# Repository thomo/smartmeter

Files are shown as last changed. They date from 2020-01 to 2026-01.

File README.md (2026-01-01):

# SmartMeter Gateway

A complete hardware solution for reading data from smart energy meters via their optical interface. This project provides the PCB designs for an IR read/write head and an ESP8266-based controller board designed to run **Tasmota**.

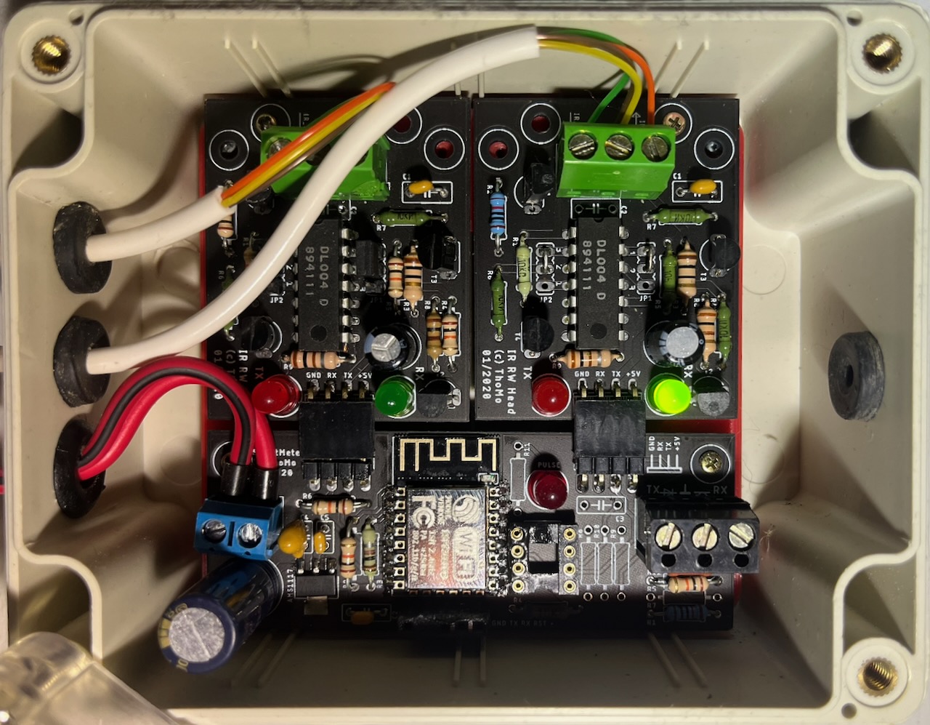
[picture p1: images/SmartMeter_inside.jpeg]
Assembled SmartMeter Gateway

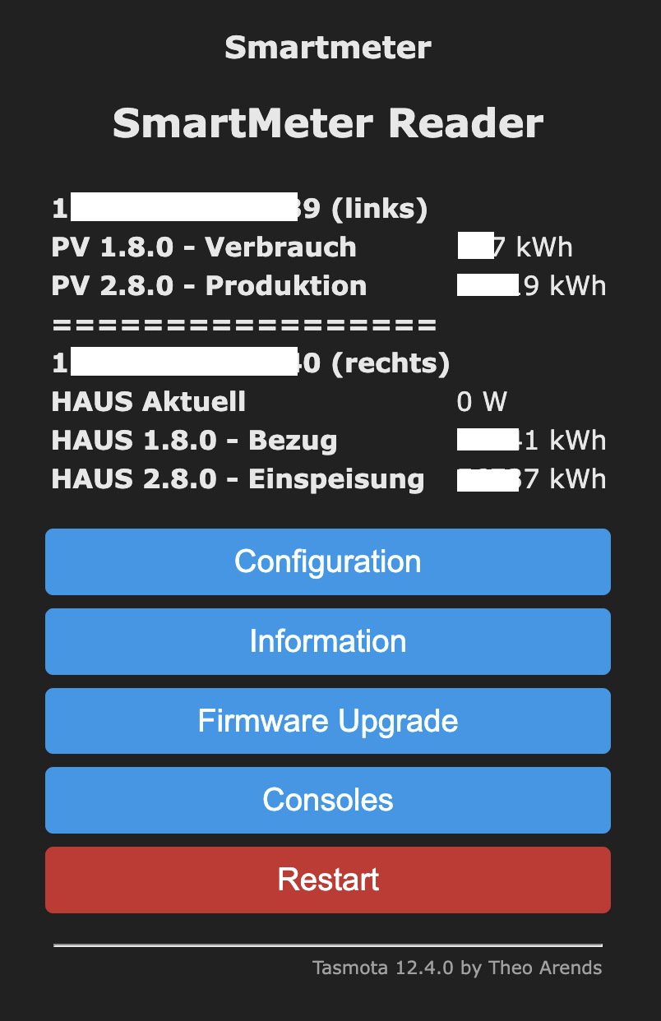
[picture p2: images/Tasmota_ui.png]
Tasmota UI


## Overview

The SmartMeter Gateway consists of two primary components:
1.  **IR Read/Write Head**: An optical probe that attaches to the smart meter's IR port.
2.  **ESP8266 Controller Board**: A carrier board for an ESP8266 module (e.g., ESP-12F) that processes the IR signals and provides a network interface via Wi-Fi.

By running Tasmota on the ESP8266, the meter data can be easily integrated into Home Automation systems like **Home Assistant**, **OpenHAB**, or **ioBroker** using MQTT or REST API.

## Hardware

The PCB designs are located in the `board` directory. These files were created with Autocad Eagle.

### 1. IR Read/Write Head (`board/ir_rw_head`)
The IR head is responsible for the physical communication with the energy meter.
- **Schematic**: [ir_rw_head_circuit.pdf](board/ir_rw_head_circuit.pdf)
- **Files**: Eagle schematic (`.sch`) and PCB layout (`.brd`).
- **Visuals**: 
    - [Top View](board/ir_rw_head_pcb_top.png)
    - [Bottom View](board/ir_rw_head_pcb_bottom.png)

### 2. ESP8266 Controller Board (`board/smartmeter`)
The main board that houses the ESP8266 and connects to the IR head.
- **Schematic**: [smartmeter_circuit.pdf](board/smartmeter_circuit.pdf)
- **Files**: Eagle schematic (`.sch`) and PCB layout (`.brd`).
- **Visuals**:
    - [Top View](board/smartmeter_pcb_top.png)
    - [Bottom View](board/smartmeter_pcb_bottom.png)

## Software / Firmware

The board is designed to be used with the [Tasmota](https://tasmota.github.io/docs/) firmware.

### Configuration
1. Build a customized tasmota image with SML/OBIS support 
   - see [Tasmota Smart Meter Interface](https://tasmota.github.io/docs/Smart-Meter-Interface/)
   - see [HOW TO: TASMOTA SML](https://docs.google.com/document/d/1olSGZcaE_vkdNXzN_p0zGee61xKCcK3HJe3Al00xj2g/edit?usp=sharing).
2. Configure the GPIOs for the IR receiver and transmitter.
```tasmota  
{"NAME":"Smartmeter","GPIO":[1,1,1,1,1,1,1,1,0,0,1,1,1,0],"FLAG":0,"BASE":18}
```

3. Use a Tasmota Script (SML) to decode the specific data format of your energy meter (e.g., SML or OBIS) - do not forget to enable the "Enable Script" checkbox. 

Example Tasmota SML script snippet:
```tasmota
>D

>B
=>sensor53 r
>M 2
+1,13,s,0,9600,Haus
+2,12,s,0,9600,PV

;1,77070100100700FF@1,Aktuell,W,Power_curr,0
1,77070100010800FF@1000,Bezug,kWh,Tariflos,2
1,77070100020800FF@1000,Einspeisung,kWh,Tariflos,2
2,=h============
;2,77070100100700FF@1,Aktuell,W,Power_curr,0
2,77070100010800FF@1000,Verbrauch,kWh,Tariflos,2
2,77070100020800FF@1000,Produktion,kWh,Tariflos,2
#
```

## Assembly

Detailed images of the assembled boards can be found in the `images` folder.
- [Inside View](images/SmartMeter_inside.jpeg)

## License

Standard open-source licenses apply. See design files for details.

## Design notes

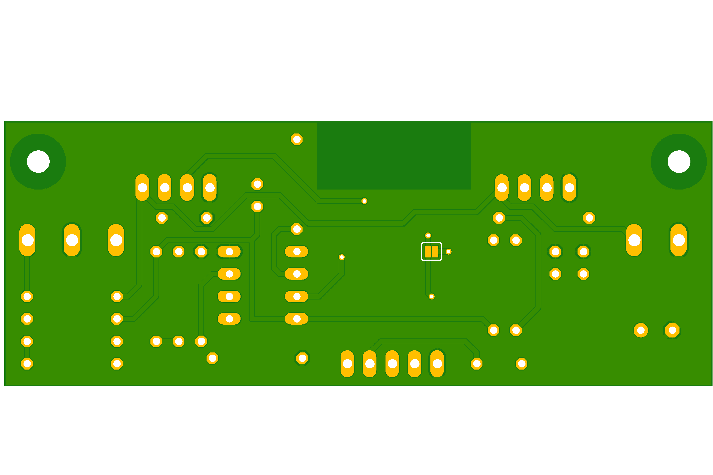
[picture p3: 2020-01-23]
board/smartmeter_pcb_bottom.png

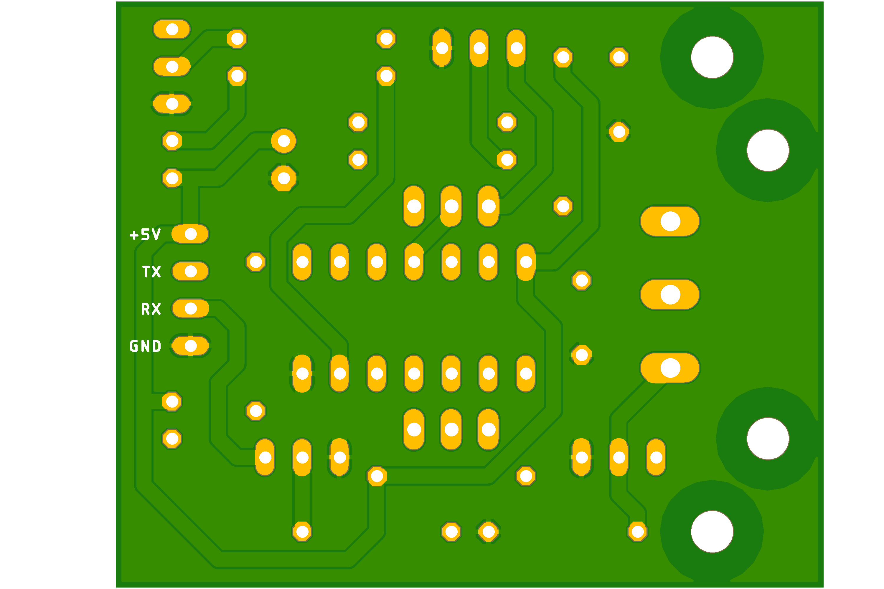
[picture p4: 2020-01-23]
board/ir_rw_head_pcb_bottom.png

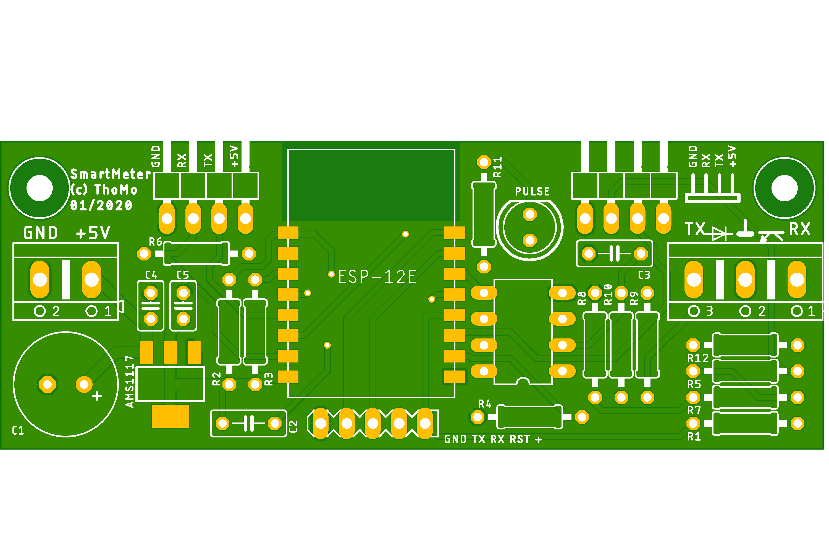
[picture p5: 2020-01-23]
board/smartmeter_pcb_top.png

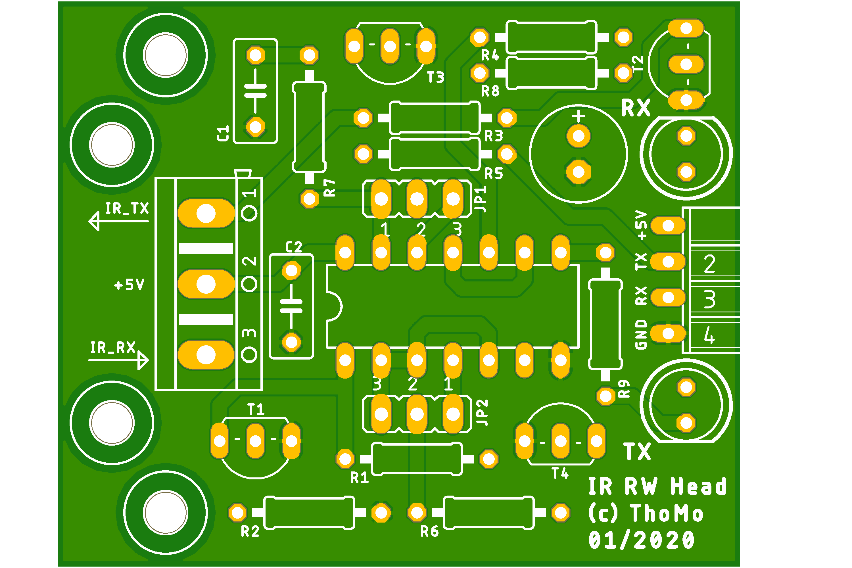
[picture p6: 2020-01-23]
board/ir_rw_head_pcb_top.png

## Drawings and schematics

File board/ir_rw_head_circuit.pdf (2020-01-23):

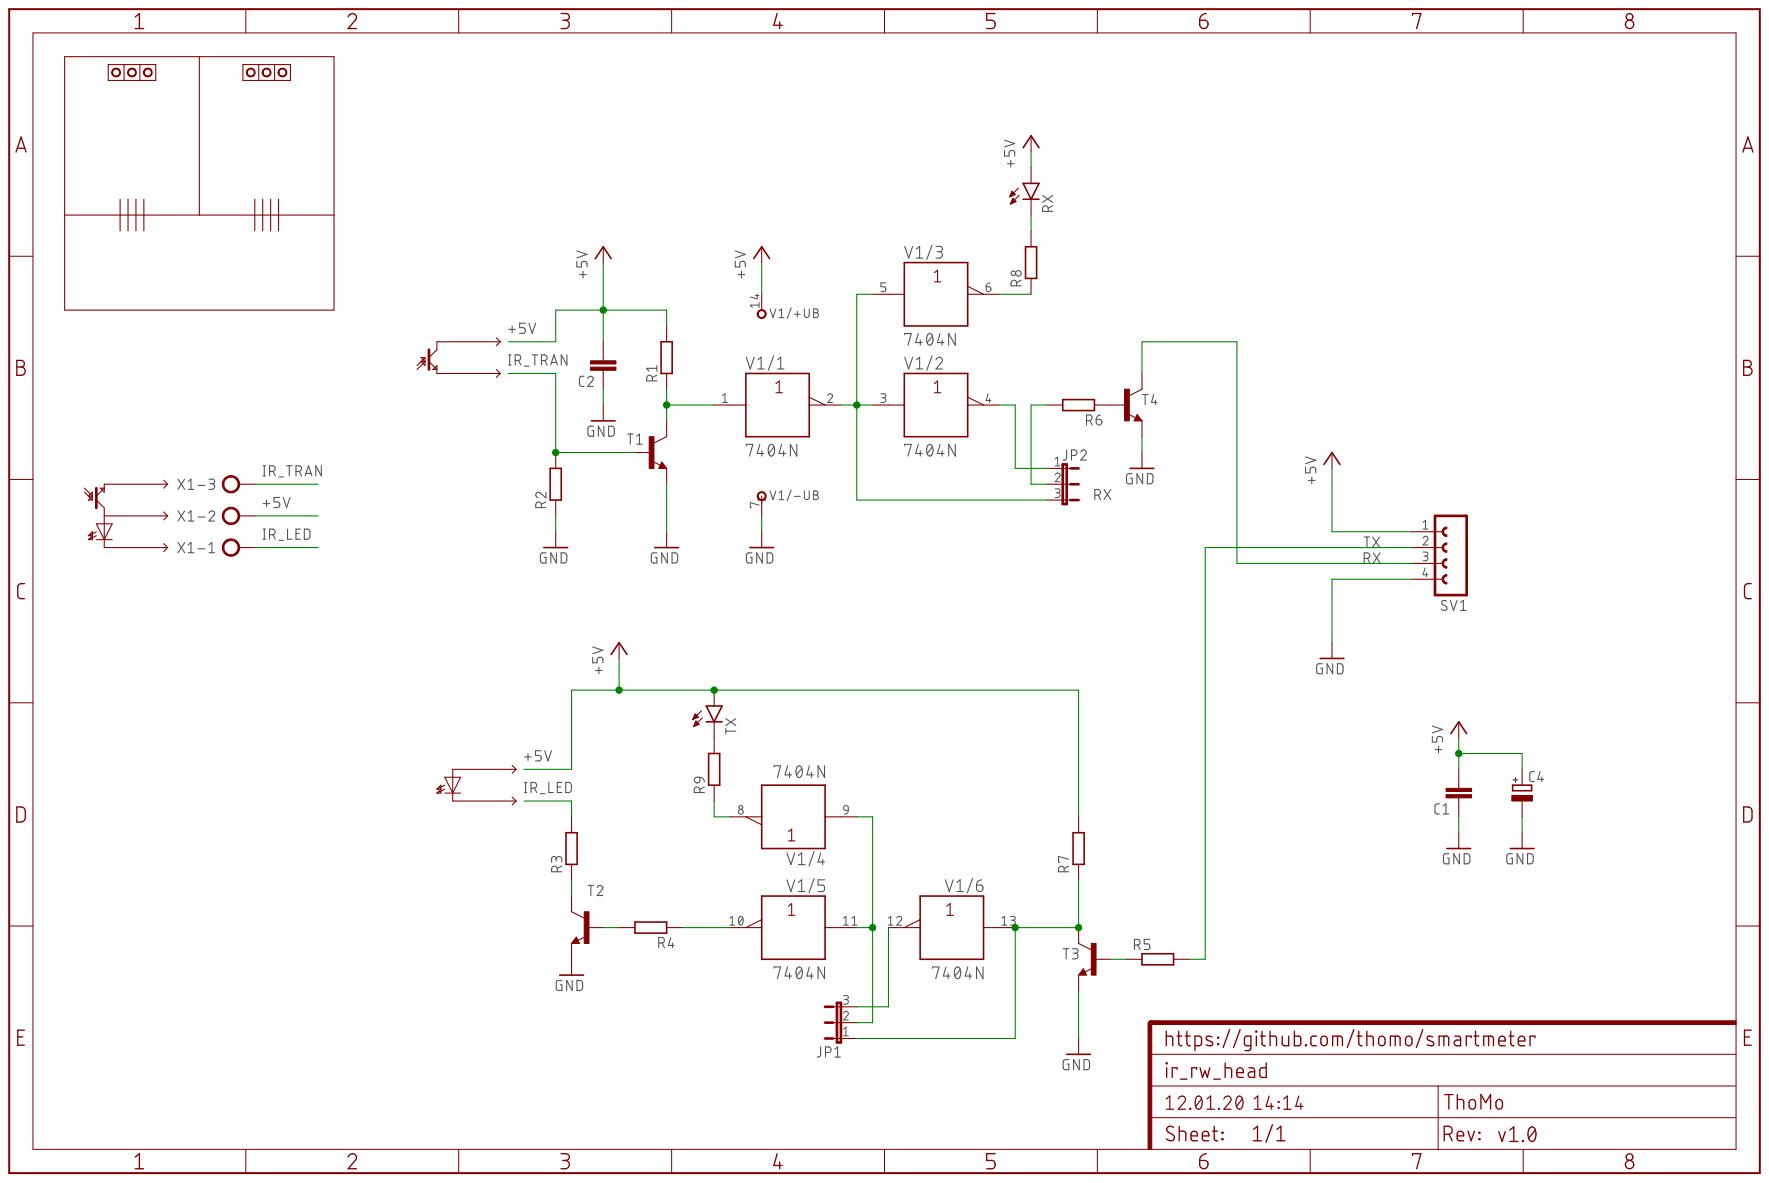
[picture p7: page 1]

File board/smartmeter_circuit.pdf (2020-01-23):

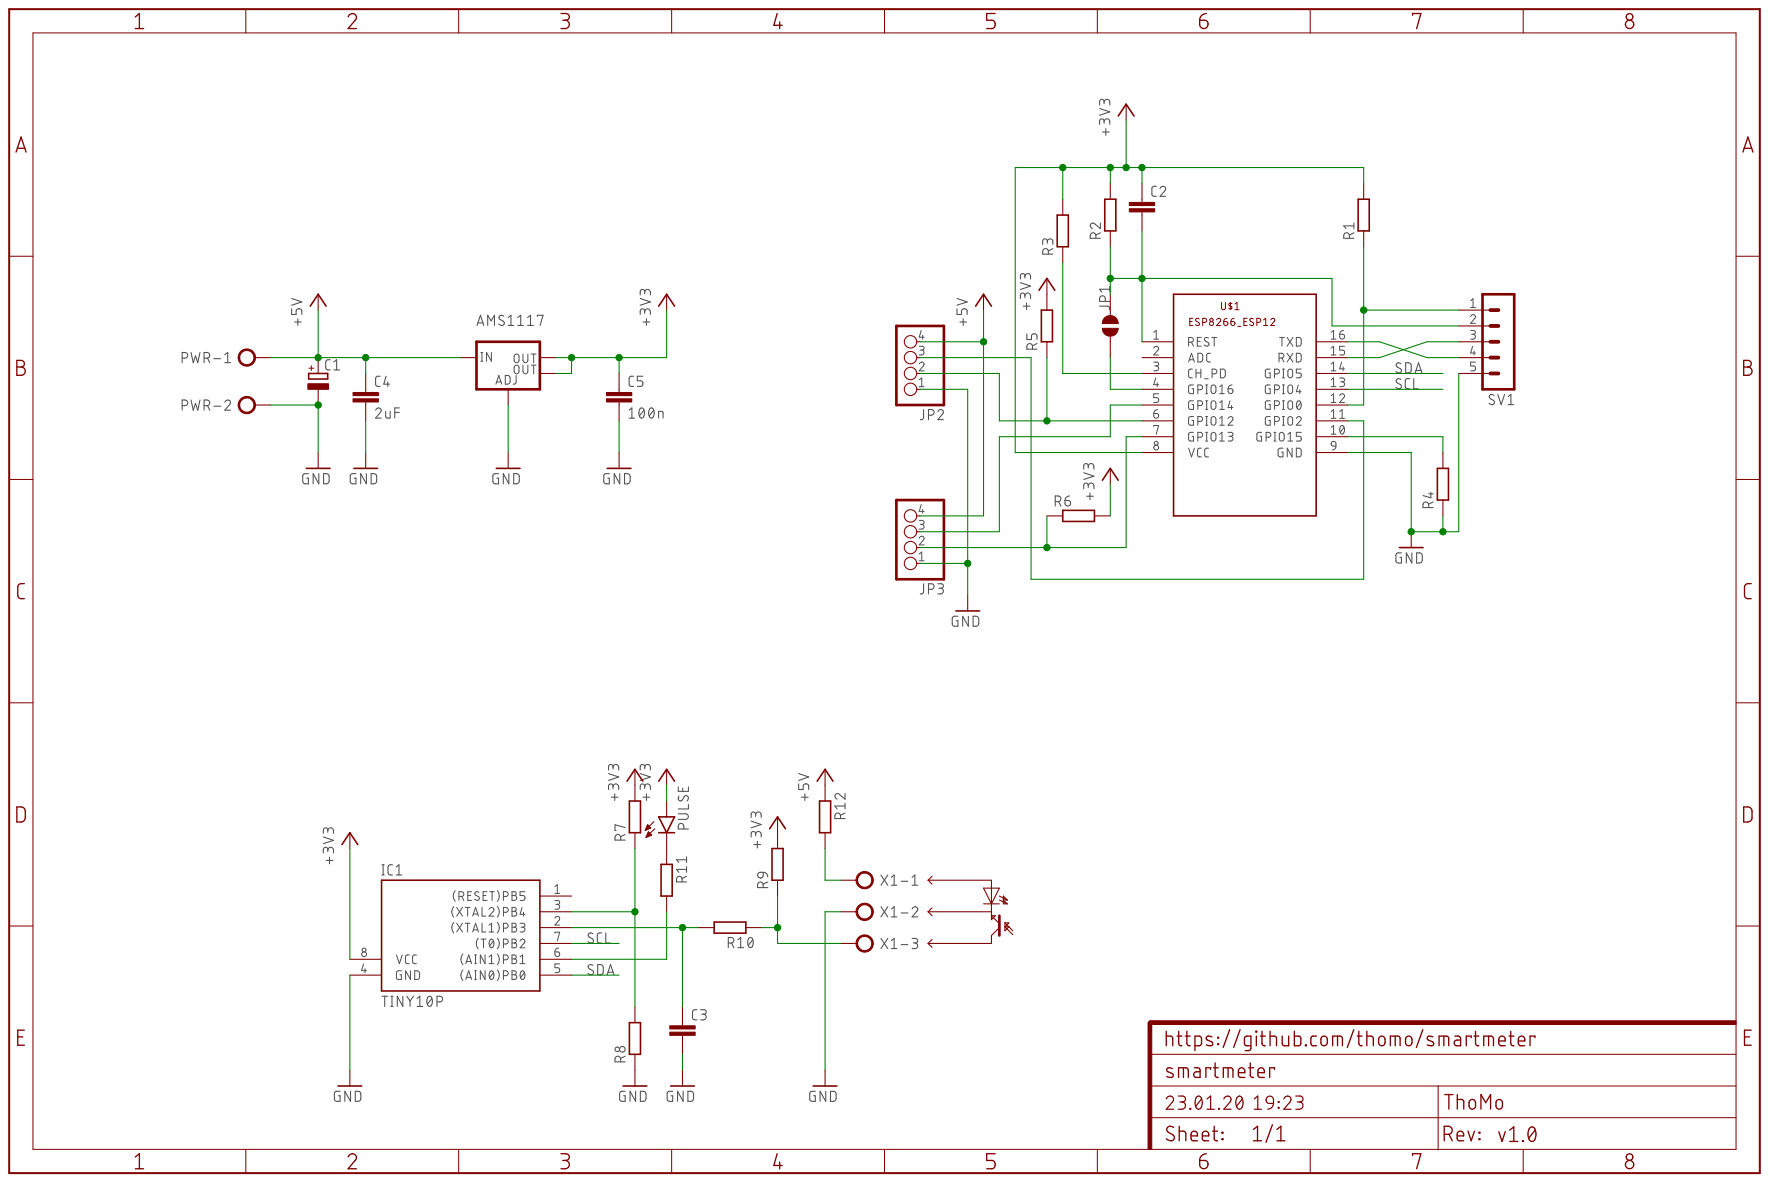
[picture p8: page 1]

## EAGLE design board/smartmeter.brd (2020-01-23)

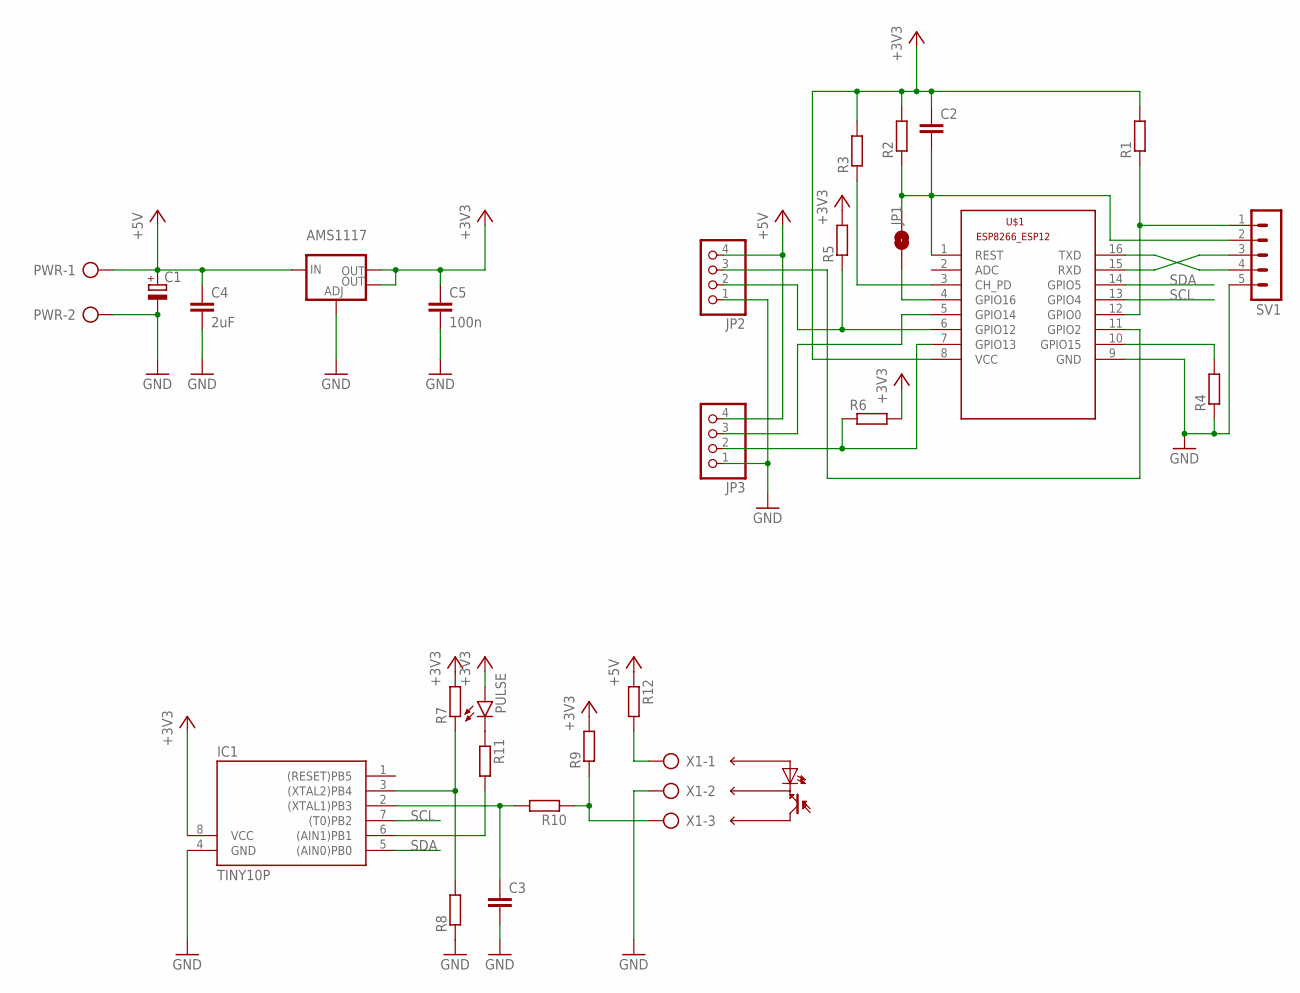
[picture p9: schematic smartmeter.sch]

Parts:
AMS1117: V_REG_LM1117SOT223; SOT223
C1: CPOL-EUE3.5-10; E3,5-10
C2, C3: C-EU050-025X075; C050-025X075
C4: 2uF; C025-025X050
C5: 100n; C025-025X050
IC1: TINY10P; DIL08
JP1: JUMPER-SMT_2_NO_SILK; SMT-JUMPER_2_NO_SILK
JP2, JP3: PINHD-1X4/90; 1X04/90
PULSE: LED5MM
PWR: AK500/2
R1, R2, R3, R4, R5, R6, R7, R8, R9, R10, R11, R12: R-EU_0207/10; 0207/10
SV1: MA05-1
U$1: ESP8266-12; ESP8266-ESP12
X1: AK500/3

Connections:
+3V3: AMS1117.2 (OUT), AMS1117.4 (OUT), C2.1, C5.1, IC1.8 (VCC), PULSE.A, R1.2, R2.2, R3.2, R5.2, R6.2, R7.2, R9.2, U$1.8 (VCC)
+5V: AMS1117.3 (IN), C1.+, C4.1, JP2.4, JP3.4, PWR.1, R12.1
GND: AMS1117.1 (ADJ), C1.-, C3.2, C4.2, C5.2, IC1.4 (GND), JP2.1, JP3.1, PWR.2, R4.1, R8.1, SV1.5, U$1.9 (GND), X1.2
unnamed: R1.1, SV1.1, U$1.12 (GPIO0)
unnamed: C2.2, JP1.2, R2.1, SV1.2, U$1.1 (REST)
unnamed: R4.2, U$1.10 (GPIO15)
unnamed: JP1.1, U$1.4 (GPIO16)
unnamed: R3.1, U$1.3 (CH_PD)
unnamed: SV1.4, U$1.16 (TXD)
unnamed: SV1.3, U$1.15 (RXD)
unnamed: C3.1, IC1.2 ((XTAL1)PB3), R10.2
unnamed: IC1.3 ((XTAL2)PB4), R7.1, R8.2
unnamed: JP2.3, U$1.11 (GPIO2)
unnamed: JP2.2, R5.1, U$1.6 (GPIO12)
unnamed: JP3.3, U$1.5 (GPIO14)
unnamed: JP3.2, R6.1, U$1.7 (GPIO13)
unnamed: R9.1, R10.1, X1.3
unnamed: IC1.6 ((AIN1)PB1), R11.2
unnamed: PULSE.K (C), R11.1
unnamed: R12.2, X1.1
SCL: IC1.7 ((T0)PB2), U$1.13 (GPIO4)
SDA: IC1.5 ((AIN0)PB0), U$1.14 (GPIO5)

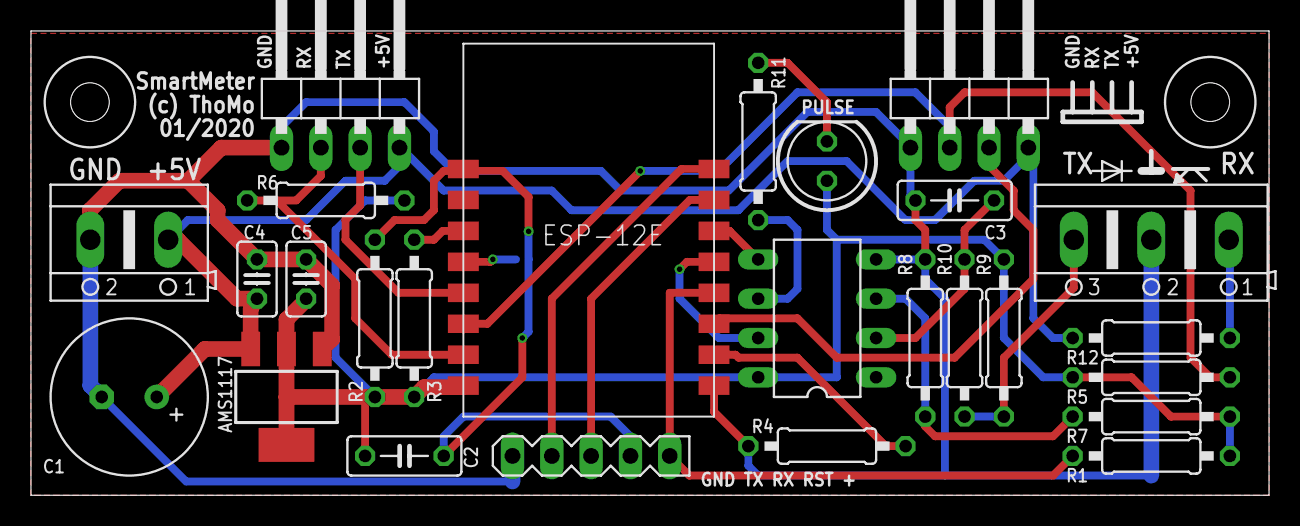
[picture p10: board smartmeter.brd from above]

Board: 2 copper layers, 80.0 x 30.0 mm, 29 parts (1 on the bottom side), 22 nets.

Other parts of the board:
U$2, U$3: DRIL-2,5

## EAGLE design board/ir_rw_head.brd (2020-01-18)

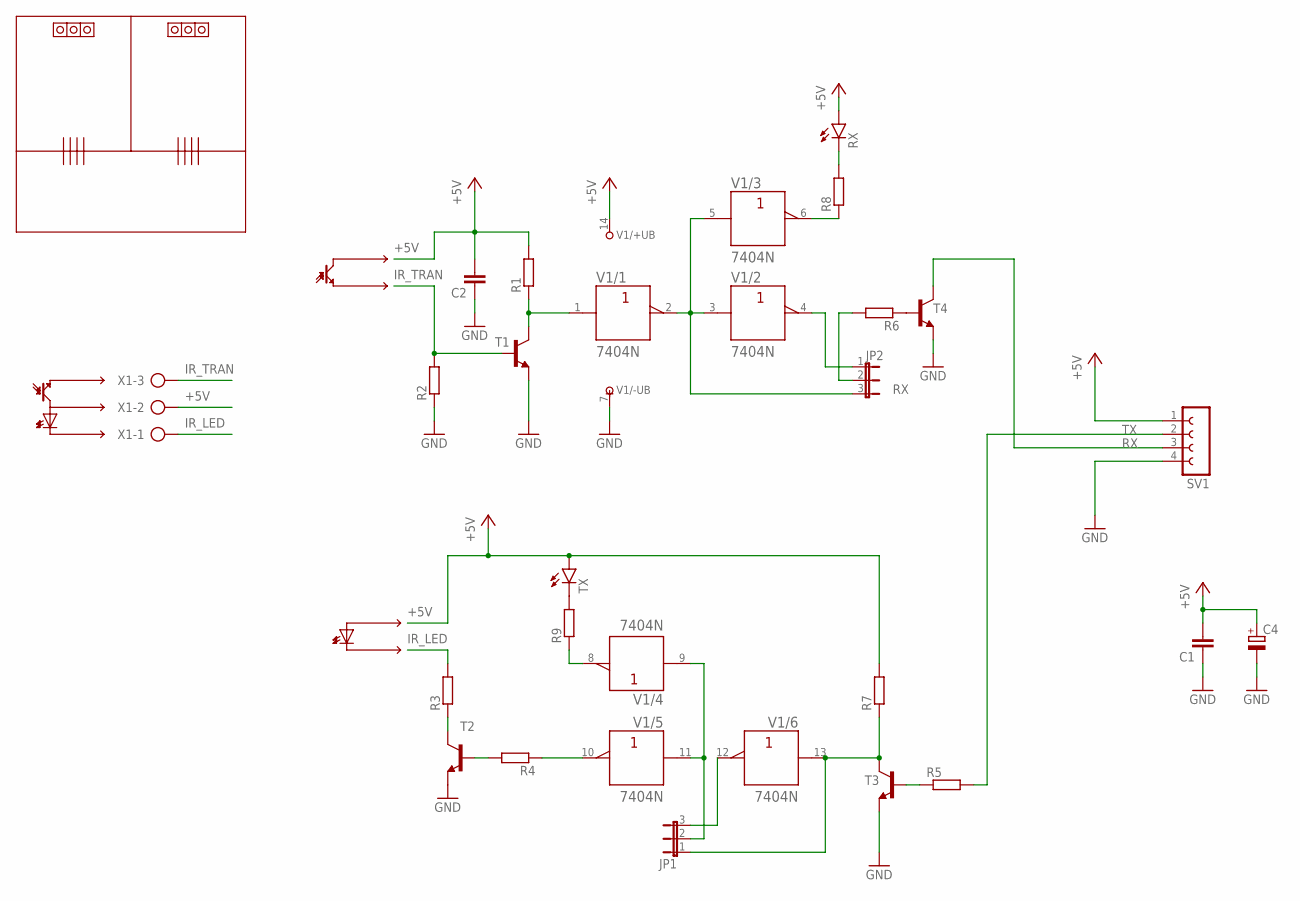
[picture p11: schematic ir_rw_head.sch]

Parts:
C1, C2: C-EU050-030X075; C050-030X075
C4: CPOL-EUE2.5-7; E2,5-7
JP1, JP2: JP2E; JP2
R1, R2, R3, R4, R5, R6, R7, R8, R9: R-EU_0207/10; 0207/10
RX: LED5MM
SV1: FE04-1W
T1, T2, T3, T4: -NPN-TO92-EBC; TO92-EBC
TX: LED5MM
V1: 7404N; DIL14
X1: AK500/3

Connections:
+5V: C1.2, C2.2, C4.+, R1.2, R7.2, RX.A, SV1.1, TX.A, V1.14 (+UB), X1.2
GND: C1.1, C2.1, C4.-, R2.1, SV1.4, T1.E, T2.E, T3.E, T4.E, V1.7 (-UB)
IR_LED: R3.2, X1.1
IR_TRAN: R2.2, T1.B, X1.3
unnamed: R4.2, T2.B
unnamed: R3.1, T2.C
unnamed: R4.1, V1.10 (Y)
unnamed: JP1.1, R7.1, T3.C, V1.13 (A)
unnamed: R5.1, T3.B
unnamed: R8.2, RX.K (C)
unnamed: R1.1, T1.C, V1.1 (A)
unnamed: JP2.3, V1.2 (Y), V1.3 (A), V1.5 (A)
unnamed: R9.2, TX.K (C)
unnamed: R6.1, T4.B
unnamed: JP2.2, R6.2
unnamed: JP2.1, V1.4 (Y)
unnamed: R8.1, V1.6 (Y)
unnamed: R9.1, V1.8 (Y)
unnamed: JP1.3, V1.12 (Y)
RX: SV1.3, T4.C
TX: R5.2, SV1.2
TX_L: JP1.2, V1.9 (A), V1.11 (A)

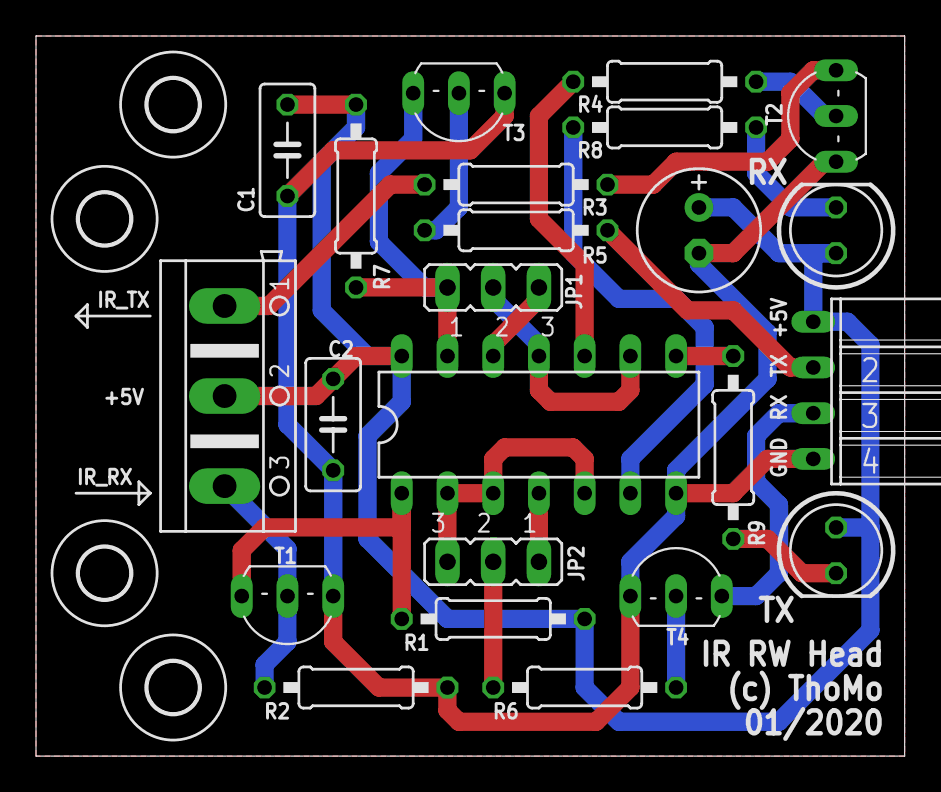
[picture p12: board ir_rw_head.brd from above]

Board: 2 copper layers, 48.3 x 40.0 mm, 27 parts (0 on the bottom side), 22 nets.

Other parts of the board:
U$1, U$2, U$3, U$4: 2,8

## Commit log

2020-01-18 PCB IR header and master
    [ir_rw_head.brd, ir_rw_head.sch, smartmeter.brd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]
2020-01-23 set frame vars and add pictures
    [smartmeter.sch]
2020-01-23 init board code
2020-01-23 update DRC rules
    [smartmeter.brd]

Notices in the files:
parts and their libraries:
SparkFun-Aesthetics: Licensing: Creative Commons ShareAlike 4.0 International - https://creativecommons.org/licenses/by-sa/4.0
